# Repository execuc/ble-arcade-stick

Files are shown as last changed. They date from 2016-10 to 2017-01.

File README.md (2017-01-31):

BLUETOOTH ARCADE STICK
==========

Project in three part to create a bluetooth arcade stick:
 * [PCB](https://github.com/execuc/ble-arcade-stick/tree/master/pcb)
 * [Bluetooth firmware on NRF51822](https://github.com/execuc/ble-arcade-stick/tree/master/firmware)
 * [Laser cut enclosure with FreeCAD](https://github.com/execuc/ble-arcade-stick/tree/master/cad)

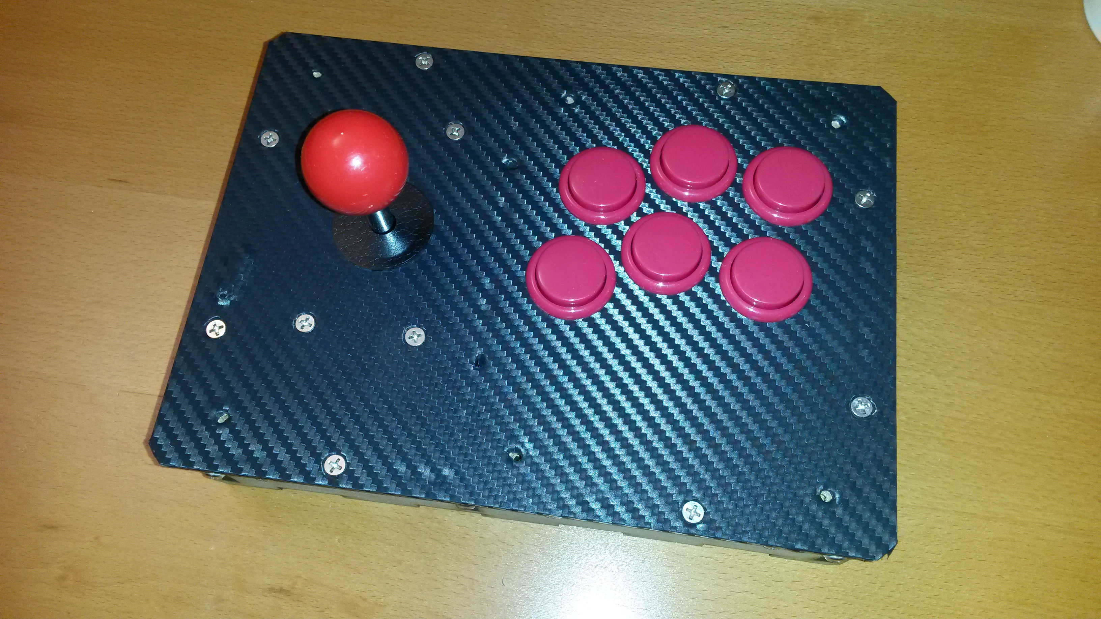
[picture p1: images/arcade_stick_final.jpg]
Illustration


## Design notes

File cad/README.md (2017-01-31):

BLUETOOTH ARCADE OR JOYSTICK CAD
==========

Arcade stick enclosure in 6mm MDF. 

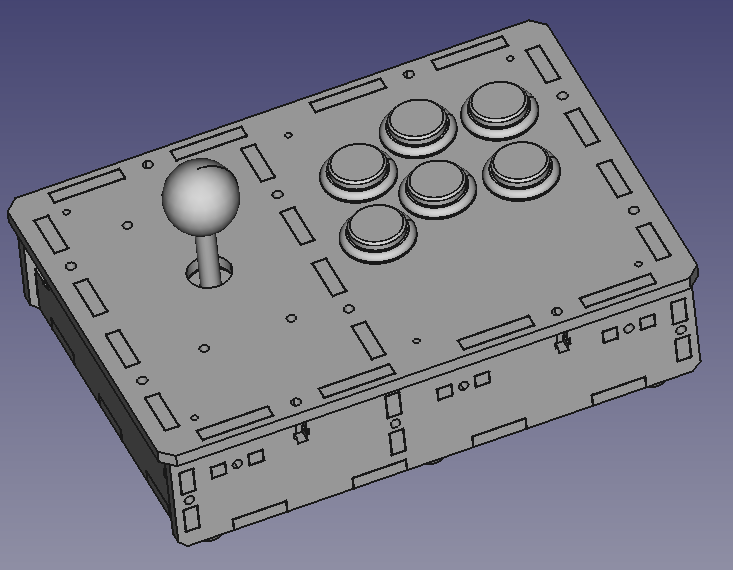
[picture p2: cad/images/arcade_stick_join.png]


**Caution** : This [SVG file](https://github.com/execuc/ble-arcade-stick/blob/master/cad/arcade-tol0_8-slot1_placed.svg) has not been still cut so I do not know if he has designs errors.

It was made with [LCInterlocking](https://github.com/execuc/LCInterlocking) FreeCAD module. It allow to design parts in 3D with 
interlocking. Then parts are projected on plane in order to export in SVG file.

The stick is designed to use cheap buttons and stick kits. There 6 30mm buttons 2 24mm buttons, 20mm hole for power switch.
It uses mainly T-Slot with M4*20mm.

LCInterlocking parameters are :
 * Laser kerf : 0.29mm
 * Thickness tolerance : 0,8mm => 0.2mm (6mm MDF thickness tolerance) + 0.6
 * Slot witdh tolerance : 1mm

There are three files :
 * arcade_stick.fcstd : FreeCAD without interlocking.
 * arcade_stick_join.fcstd : FreeCAD with interlocking.
 * arcade-tol0_8-slot1_placed.svg : file to laser cut.

Images
======

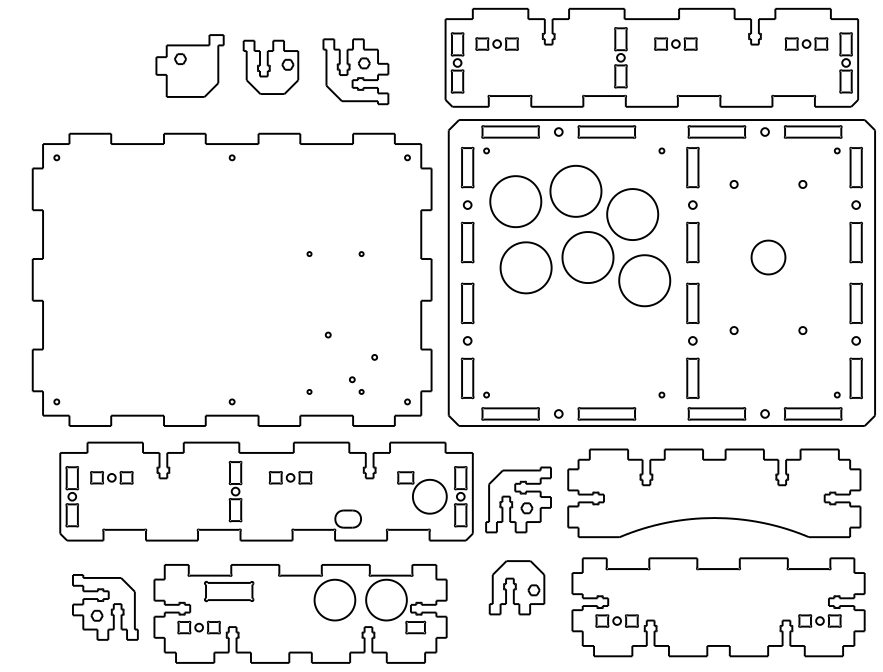
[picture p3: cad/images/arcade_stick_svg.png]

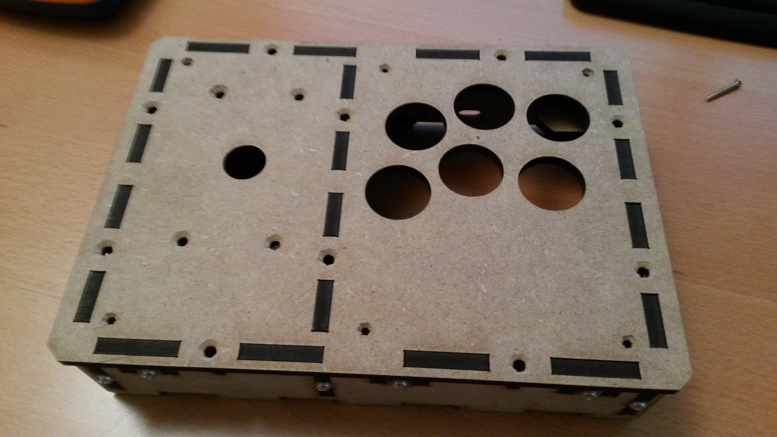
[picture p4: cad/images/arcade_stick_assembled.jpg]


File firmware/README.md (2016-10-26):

BLUETOOTH ARCADE OR JOYSTICK PCB FIRMWARE
==========

This document assumes using an NRF51822 Rev3 (ac) with 256KB of flash and 32KB of RAM. The whole project is
not provided because NordicSemiconductor examples are not opensource. So diff files and instruction are
explained here to build the firmware.

Two firmwares can be compiled for different uses:
 * Arcade : 2 digital axis with 10 buttons.
 * Analog : 5 analog axis with 14 buttons (not working).

**Caution** : Firmwares have to be tested. Analog firmware does not work during adc sampling. In fact, adc sampling is launched on
BLE_GAP_EVT_CONNECTED but leads to disconnection (peripheral or central?). It seems adc routines block ble bonding process and disconnect.

Download nRF5_SDK_12.1.0_0d23e2a and extract it to nrf_sdk12 directory.
In file components/ble/ble_radio_notification/ble_radio_notification.c, add #include "nrf_nvic.h" after #include <stdlib.h>.

Duplicate examples/ble_peripheral/ble_app_hids_keyboard to examples/ble_peripheral/nrf51_hid_joy.

Remove inside:
 * pca10040 
 * hex/*.hex
 * pca10028/s130/arm4
 * pca10028/s130/iar
 * ble_app_hids_keyboard.eww
 * pca10028/s130/arm5_no_packs/RTE/Device

Apply patch to (patch filename < patch_file):
 * main.c (main.patch)
 * pca10028/s130/config/sdk_config.h (sdk_config.patch)
 * pca10028/s130/armgcc/Makefile (makefile.patch)

Add files:
 * time.c
 * time.h
 * joy.c
 * joy.h

With Keil UVision :
Add files to project ("Add files to group appplication"):
 * joy.c
 * joy.h
 * time.c
 * time.h

Remove files or group:
 * Board Support Group
 * sensorsim.c on nRF_librairies
 * app_button.c on nRF_librairies
 * Add components/drivers_nrf/timer/nrf_drv_timer.c to nRF_Drivers group
 * Add components/drivers_nrf/nrf_soc_nosd/nrf_nvic.c to nRF_Drivers group
 * Add components/ble/ble_radio_notification/ble_radio_notification.c to nRF_BLE group

In the target option view: 
 * Change C/C++ and ASM define :
	* Remove BOARD_PCA10028
	* Replace NRF51422 by NRF51822
	* Add NRF_LOG_ENABLED=1 to enable UART log NRF_LOG_ENABLED=0 to disable it.
	* Add DEBUG to enable debug purposes.
	* Add BLE400 for test with Waveshare BLE400 development board (Use buttons 1 and 2 for all input).
	* Add ARCADE_INPUT for arcade firmware (default) or ANALOG_INPUT for analog firmware.
 * C/C++ Include paths:
    * Add ..\..\..\..\..\..\components\ble\ble_radio_notification

With GCC :
On pca10028/s130/armgcc directory, launch make.

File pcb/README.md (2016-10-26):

BLUETOOTH ARCADE OR JOYSTICK PCB CONTROLLER
==========

This part contains schematic, layout and gerber files to produce a bluetooth arcade or joystick controller. It is
based on Waveshare NRF51822 module. PCB is made with EAGLE software.

**Caution** : No reverse polarity

Files
--------------------

 * nrf51_hid_joy.lbr : EAGLE library.
 * nrf51_hid_joy.sch : EAGLE schematic.
 * nrf51_hid_joy.brd : EAGLE board.
 * nrf51_hid_joy.zip : gerber files for PCB.

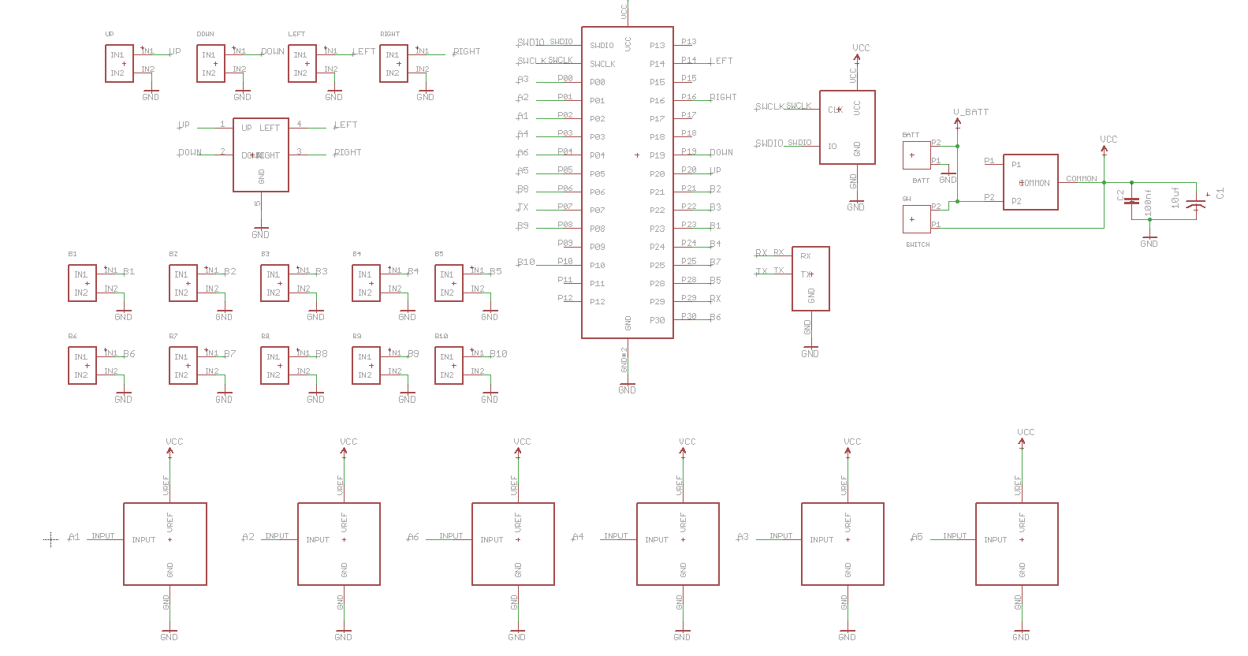
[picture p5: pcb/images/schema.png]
  
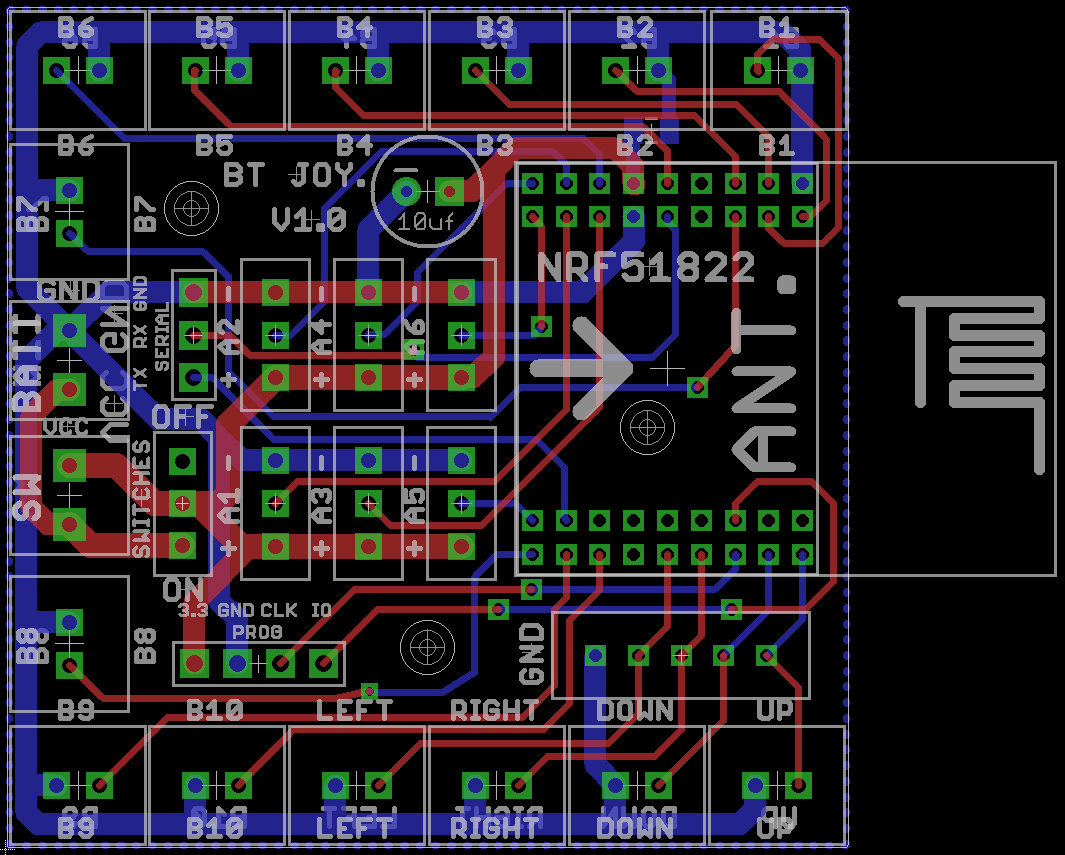
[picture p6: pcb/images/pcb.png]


DIMENSION
--------------------
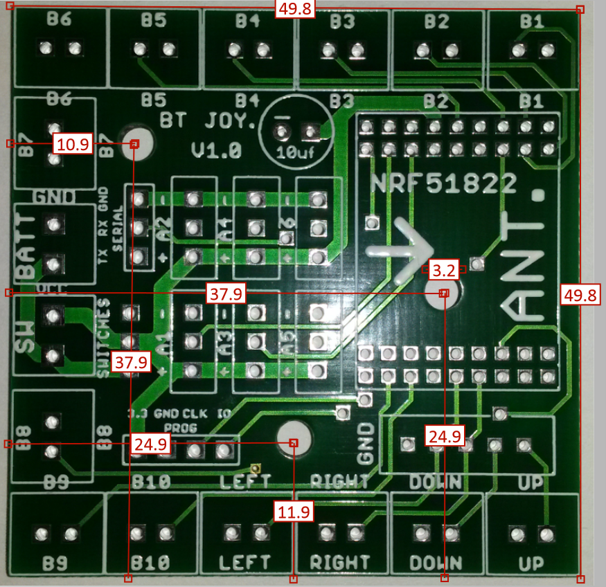
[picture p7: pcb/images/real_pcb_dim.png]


TODO
--------------------

 * Replace screw terminals (switch and supply) by JST 2.54mm.

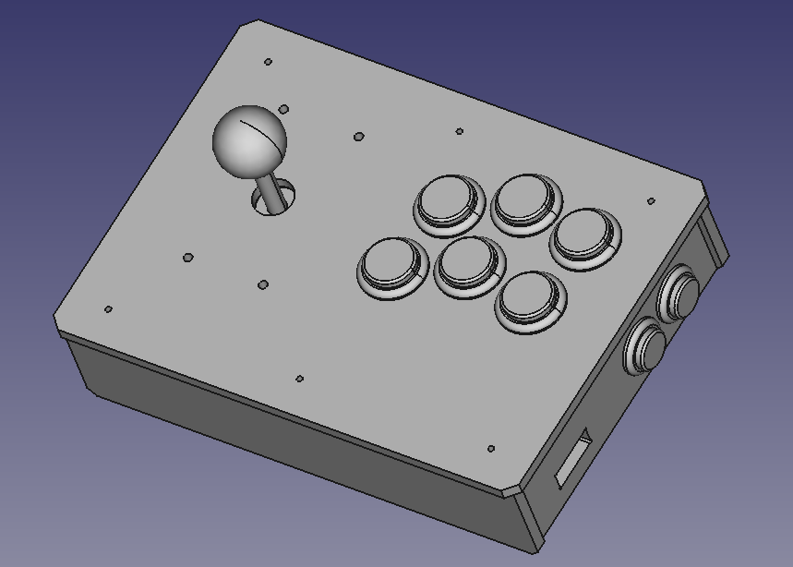
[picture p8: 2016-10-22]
cad/images/arcade_stick.png

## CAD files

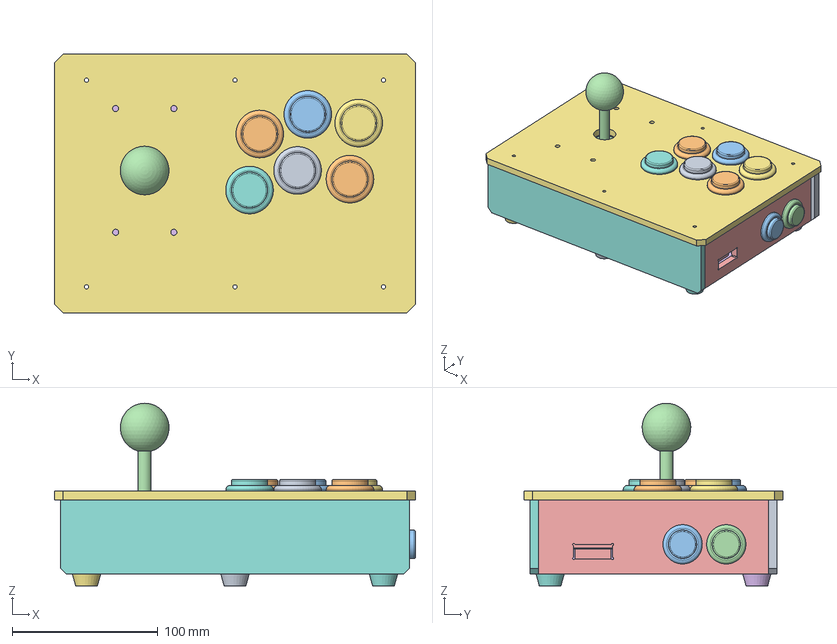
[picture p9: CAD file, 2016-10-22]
cad/arcade_stick.fcstd
248.0 x 178.0 x 125.4 mm
right_final
30mm_1
24mm_1
stick
ble_pcb
usb_pcb
30mm_2
30mm_3
30mm_4
30mm_5
30mm_6
24mm_2
aa
inside_final
left_final
bottom_final
top_final
face_final
behind_final
block_spacer_final

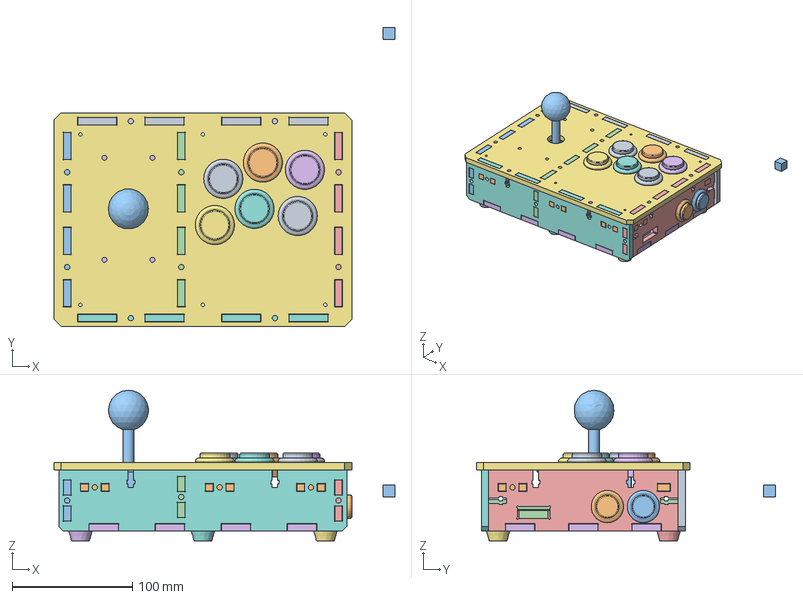
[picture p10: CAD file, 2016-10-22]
cad/arcade_stick_join.fcstd
284.0 x 249.0 x 125.4 mm
30mm_1
24mm_1
stick
ble_pcb
usb_pcb
30mm_2
30mm_3
30mm_4
30mm_5
30mm_6
24mm_2
aa
right_final_tab
inside_final_tab
left_final_tab
bottom_final_tab
top_final_tab
face_final_tab
behind_final_tab
block_spacer_final_tab

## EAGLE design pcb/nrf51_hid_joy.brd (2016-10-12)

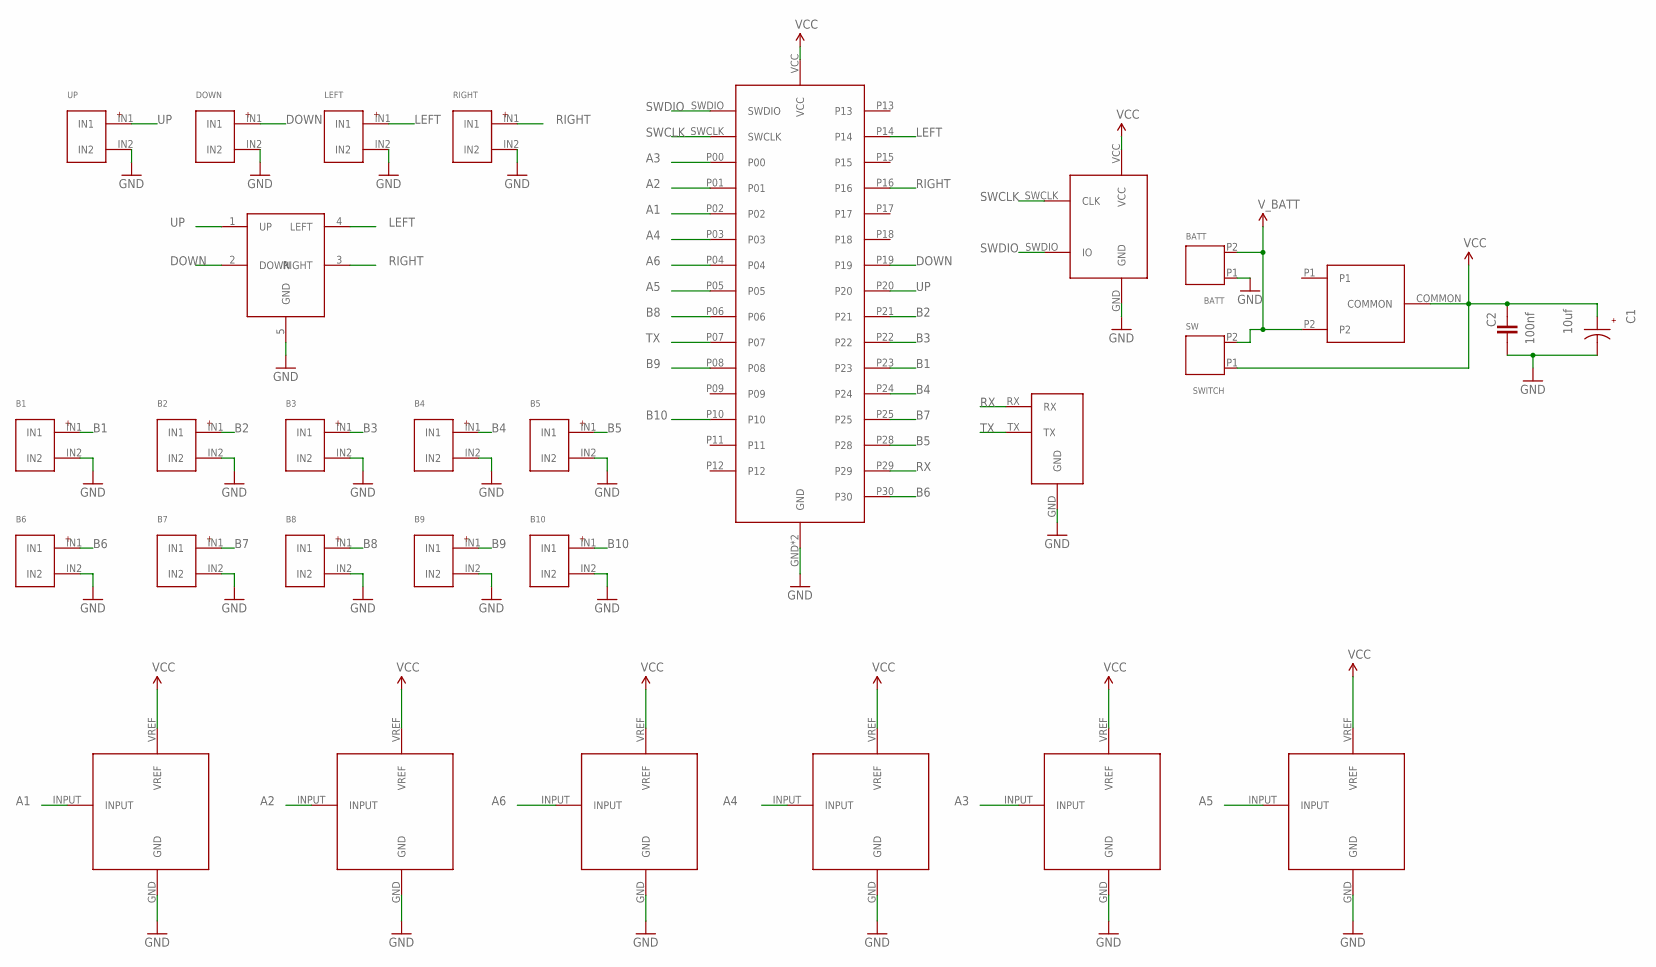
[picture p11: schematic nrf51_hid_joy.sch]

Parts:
A1: A1; ANALOG_INPUT
A2: A2; ANALOG_INPUT
A3: A3; ANALOG_INPUT
A4: A4; ANALOG_INPUT
A5: A5; ANALOG_INPUT
A6: A6; ANALOG_INPUT
B1: B1; JST254
B2: B2; JST254
B3: B3; JST254
B4: B4; JST254
B5: B5; JST254
B6: B6; JST254
B7: B7; JST254
B8: B8; JST254
B9: B9; JST254
B10: B10; JST254
BATT: BATT; 2P-3.5
C1: 10uf; CAPA-RAD-MEDIUM
C2: 100nf; 0805
DOWN: DOWN; JST254
LEFT: LEFT; JST254
RIGHT: RIGHT; JST254
SWITCH: SW; 2P-3.5
U$1: NRF51_MODULEBIG; NRF51-MODULE
U$2: NRF51_PROG; PROG_SWD
U$3: NRF51_SERIAL
U$14: 5_5PINS_JOY; 5_PINS_CONNECTOR
U$23: SWITCH; SS-12D00G3
UP: UP; JST254

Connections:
A1: A1.INPUT, U$1.P02
A2: A2.INPUT, U$1.P01
A3: A3.INPUT, U$1.P00
A4: A4.INPUT, U$1.P03
A5: A5.INPUT, U$1.P05
A6: A6.INPUT, U$1.P04
B1: B1.IN1, U$1.P23
B2: B2.IN1, U$1.P21
B3: B3.IN1, U$1.P22
B4: B4.IN1, U$1.P24
B5: B5.IN1, U$1.P28
B6: B6.IN1, U$1.P30
B7: B7.IN1, U$1.P25
B8: B8.IN1, U$1.P06
B9: B9.IN1, U$1.P08
B10: B10.IN1, U$1.P10
DOWN: DOWN.IN1, U$1.P19, U$14.2 (DOWN)
GND: A1.GND, A2.GND, A3.GND, A4.GND, A5.GND, A6.GND, B1.IN2, B2.IN2, B3.IN2, B4.IN2, B5.IN2, B6.IN2, B7.IN2, B8.IN2, B9.IN2, B10.IN2, BATT.P1 (1), C1.2 (-), C2.1, DOWN.IN2, LEFT.IN2, RIGHT.IN2, U$1.GND, U$1.GND2 (GND), U$2.GND, U$3.GND, U$14.5 (GND), UP.IN2
LEFT: LEFT.IN1, U$1.P14, U$14.4 (LEFT)
RIGHT: RIGHT.IN1, U$1.P16, U$14.3 (RIGHT)
RX: U$1.P29, U$3.RX
SWCLK: U$1.SWCLK, U$2.SWCLK (CLK)
SWDIO: U$1.SWDIO, U$2.SWDIO (IO)
TX: U$1.P07, U$3.TX
UP: U$1.P20, U$14.1 (UP), UP.IN1
VCC: A1.VREF, A2.VREF, A3.VREF, A4.VREF, A5.VREF, A6.VREF, C1.1 (+), C2.2, SWITCH.P1 (1), U$1.VCC, U$2.VCC, U$23.COMMON
V_BATT: BATT.P2 (2), SWITCH.P2 (2), U$23.P2

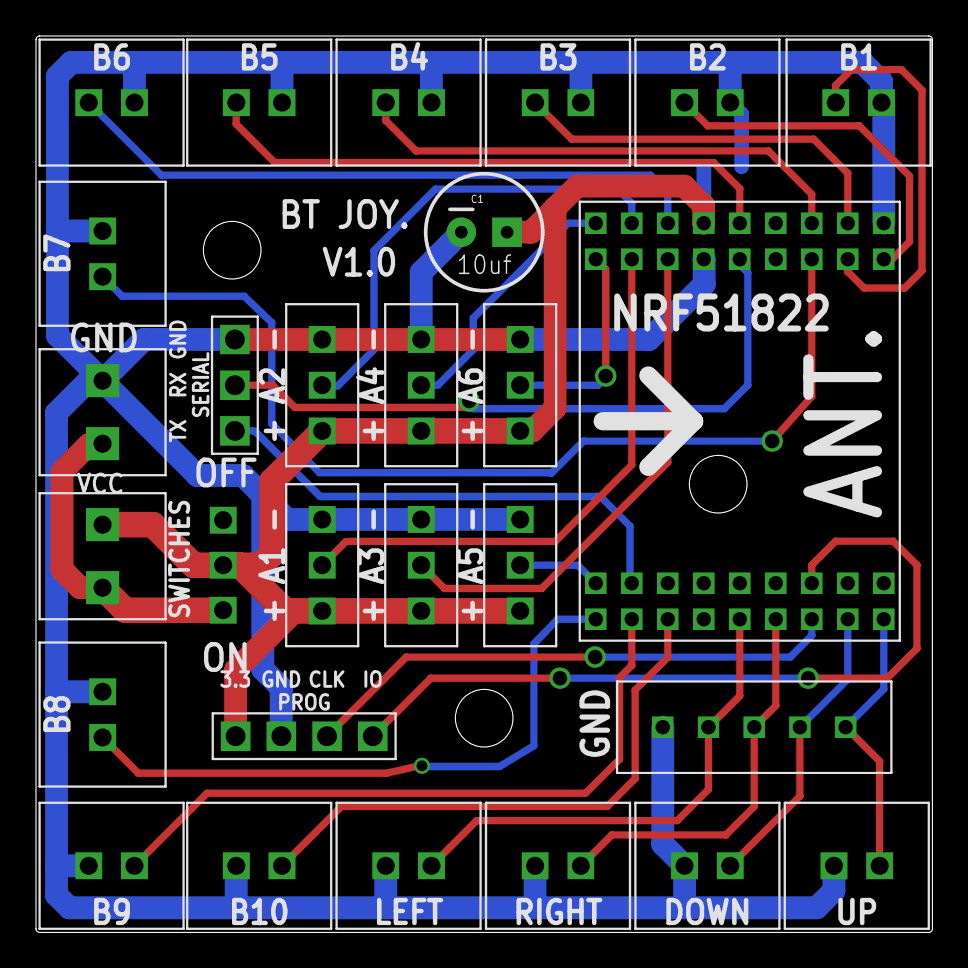
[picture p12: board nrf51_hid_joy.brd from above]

Board: 4 copper layers, 49.8 x 49.8 mm, 29 parts (1 on the bottom side), 27 nets.

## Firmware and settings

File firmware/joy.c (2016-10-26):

#include "joy.h"

#include <stdint.h>
#include <string.h>

#include "nrf_soc.h"
#include "nrf_gpio.h"
#include "nrf_log.h"
#include "nrf_adc.h"
#include "nrf_drv_common.h"
#include "time.h"


// INPUT
#define CHECK_MSEC 1 // Read hardware every 5 msec
//#define PRESS_MSEC 10 // Stable time before registering pressed
//#define RELEASE_MSEC 100 // Stable time before registering released
#define PRESS_MSEC 3 // Stable time before registering pressed
#define RELEASE_MSEC 20 // Stable time before registering released

#define INPUT_BT_NUMBER 14
static uint16_t debounced_buttons = 0x0000;
#ifndef BLE400
const uint8_t button_mapping[INPUT_BT_NUMBER] = {16, //LEFT
                                                 14, //RIGHT
                                                 19, //UP
                                                 20, //DOWN
                                                 23, //B1
                                                 21, //B2
                                                 22, //B3
                                                 24, //B4
                                                 28, //B5
                                                 30, //B6
                                                 25, //B7
                                                  6, //B8
                                                  8, //B9
                                                 10};//B10
#else
#define B1_PIN 16
#define UP_PIN 17
const uint8_t button_mapping[INPUT_BT_NUMBER] = {16, //B1
                                                 17, //B2
                                                 16, //B1
                                                 17, //B2
                                                 16, //B1
                                                 17, //B2
                                                 16, //B1
                                                 17, //B2
                                                 16, //B1
                                                 17, //B2
                                                 16, //B1
                                                 17, //B2
                                                 16, //B1
                                                 17};//B2
#endif
uint8_t debouncer_counter[INPUT_BT_NUMBER];            

// ADC
#define ADC_INTERRUPT_LEVEL 3
#define VCC_SAMPLING_NB 3
#define ADC_CORRECT_VALUE(ADC_VALUE) ((ADC_VALUE) * (1024+gain_error) / 1024 + offset_error - 0.5)
static  joy_evt_handler_t m_evt_handler = NULL;
static uint32_t adc_vcc_config =     (ADC_CONFIG_RES_10bit << ADC_CONFIG_RES_Pos) |
                                                                    (ADC_CONFIG_INPSEL_SupplyOneThirdPrescaling << ADC_CONFIG_INPSEL_Pos) |
                                                                    (ADC_CONFIG_REFSEL_VBG << ADC_CONFIG_REFSEL_Pos) |
                                                                    (ADC_CONFIG_PSEL_Disabled << ADC_CONFIG_PSEL_Pos) |
                                                                    (ADC_CONFIG_EXTREFSEL_None << ADC_CONFIG_EXTREFSEL_Pos);
static uint8_t adc_state = 0;
static int32_t adc_vcc_buffer[VCC_SAMPLING_NB];
static uint8_t adc_index_buffer = 0;
static int8_t offset_error;
static int8_t gain_error;
static void adc_init(void);

typedef enum
{
        ADC_NONE = 0,
    ADC_VCC_SAMPLING,
      ADC_CH_SAMPLING
} adc_internal_state;

#if !defined(ARCADE_INPUT)
#define CH_SAMPLING_NB 3
#define CH_NB 6
static uint32_t adc_channels_config[CH_NB];
static int32_t adc_channels_buffer[CH_SAMPLING_NB * CH_NB];
static uint8_t adc_channels_value[CH_NB];
static bool m_high_voltage = false;
static bool m_adc_converted = false;
static void convert_adc_channel(void);
static uint8_t adc_ch_index = 0;
static void update_adc_channels_param(bool high_voltage);
const uint8_t analog_mapping[CH_NB] = {2, 1, 0, 3, 5, 4};
#endif


void joy_input_init(joy_evt_handler_t callback)
{
    uint8_t index=0;
    m_evt_handler = callback;
    
    for(index=0; index < INPUT_BT_NUMBER; index++)
    {
        nrf_gpio_cfg_input(button_mapping[index], NRF_GPIO_PIN_PULLUP);
    }
#if !defined(ARCADE_INPUT)
    memset(adc_channels_value, 128, sizeof(uint8_t) * CH_NB);
#endif    
    adc_init();
    nrf_adc_event_clear(NRF_ADC_EVENT_END);
    nrf_drv_common_irq_enable(ADC_IRQn, ADC_INTERRUPT_LEVEL);
}


void joy_get_report(uint8_t *report)
{
#if defined(ARCADE_INPUT)
    report[0] = debounced_buttons & 0xF0;
    report[1] = (debounced_buttons & 0xFF00) >> 8;
    // Axis : 0 => negative || 1 neutral || 2 => positive
    if( ((debounced_buttons & 0x03) == 0) || ((debounced_buttons & 0x03) == 0x03) )
        report[0] |= 0x01;
    else if(debounced_buttons & 0x02)
        report[0] |= 0x02;
    /*else if(debounced_buttons & 0x01)
        report[0] |= 0x00;*/
    
    if( ((debounced_buttons & 0x0C) == 0) || ((debounced_buttons & 0x0C) == 0x0C) )
        report[0] |= 0x04;
    else if(debounced_buttons & 0x08)
        report[0] |= 0x08;
    /*else if(debounced_buttons & 0x04)
        report[0] |= 0x00;*/
#else
    if(m_adc_converted == false)
        convert_adc_channel();
    memcpy(&(report[0]), adc_channels_value, sizeof(uint8_t) * CH_NB);
    report[6] = debounced_buttons & 0xF0;
    report[7] = (debounced_buttons & 0xFF00) >> 8;
#endif    
}


// debouncing : http://stackoverflow.com/questions/155071/simple-debounce-routine
bool joy_debounce_input(void)
{
    uint8_t index;
    bool state_changed = false;
    //NRF_LOG_INFO("%zu:debounce\r\n", micros());
    
    for(index=0; index < INPUT_BT_NUMBER; index++)
    {
        bool rawState = !nrf_gpio_pin_read(button_mapping[index]);
        bool debouncedState = debounced_buttons & (0x01 << index);
        if(rawState == debouncedState)
        {
            if(debouncedState)
                debouncer_counter[index] = RELEASE_MSEC / CHECK_MSEC;
            else
                debouncer_counter[index] = PRESS_MSEC / CHECK_MSEC;
        }
        else
        {
            // Key has changed - wait for new state to become stable.
            if (--(debouncer_counter[index]) == 0) 
            {
                // Timer expired - accept the change.
                if(rawState)
                {
                    debounced_buttons |= (0x01 << index);
                    debouncer_counter[index] = RELEASE_MSEC / CHECK_MSEC;
                }
                else
                {
                    debounced_buttons &= ~(0x01 << index);
                    debouncer_counter[index] = PRESS_MSEC / CHECK_MSEC;
                }
                state_changed = true;
            }
        }
    }
    return state_changed;
}


void joy_input_reset(void)
{
    debounced_buttons = 0x0000;
    memset(debouncer_counter, PRESS_MSEC / CHECK_MSEC, sizeof(debouncer_counter));
}
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

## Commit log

2016-10-12 First commit
    Add PCB part.
    [nrf51_hid_joy.brd, nrf51_hid_joy.sch]
2016-10-12 Correct first commit
    [nrf51_hid_joy.brd, nrf51_hid_joy.sch]
2016-10-22 Add CAD files
    [arcade_stick.fcstd, arcade_stick_join.fcstd]
2016-10-26 Misc.
    Invert Up/Down Left/Right axis.
    [joy.c]
